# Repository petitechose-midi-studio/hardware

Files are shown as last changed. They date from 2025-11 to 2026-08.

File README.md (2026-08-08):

# MIDI Studio - Hardware Design

Open-source hardware design files for the MIDI Studio controller.

**Teensy 4.1 based MIDI controller with ILI9341 display, 10 rotary encoders, and 15 buttons.**

---

## Hardware Specifications

### Core Components

- **MCU:** Teensy 4.1 (ARM Cortex-M7; hardware rated up to 600 MHz, with MIDI Studio firmware configured at 450 MHz)
- **RAM:** 8 MB PSRAM (**mandatory** - soldered on underside pads)
- **Display:** ILI9341 2.8" TFT (320x240, SPI)
- **Encoders:**
  - 8x Bourns PEC11R rotary encoders (24 PPR, smooth, with push button)
  - 1x Bourns PEC11R rotary encoder (24 PPR, detented, with push button)
  - 1x E38S6G5 optical encoder (600 PPR, high-resolution)
- **Button inputs:** 15 total (6x panel tactile switches + 8x macro-encoder push switches through the multiplexer, plus the NAV encoder push directly on MCU pin 32)
- **Multiplexer:** CD74HC4067 (16-channel analog multiplexer; 14 button inputs used)
- **Connectivity:** USB MIDI (USB-B connector)

### Display Interface (SPI)

- CS = Pin 28
- DC = Pin 0
- RST = Pin 29
- MOSI = Pin 26
- SCK = Pin 27
- MISO = Pin 1
- Firmware-configured SPI speed: 50 MHz

### Power

- USB-powered (5V)
- Teensy 4.1 regulates to 3.3V for peripherals

---

## Repository Contents

### `pcb/`

KiCad PCB design files and manufacturing outputs.

```
pcb/kicad/
midi-studio.kicad_pro      # KiCad project
midi-studio.kicad_sch      # Schematic
midi-studio.kicad_pcb      # PCB layout
midi-studio.step           # 3D model
gerbers/                   # Gerber files for PCB fabrication
bom/                       # Bill of Materials + CPL
pdf/                       # Schematic and assembly drawings (PDF)
```

**PCB Specifications:**
- Layers: 2-layer PCB
- Thickness: 1.6mm
- Surface finish: HASL or ENIG
- Compatible: JLCPCB, PCBWay, OSH Park

---

### `cnc/`

CNC machining files for enclosure fabrication (G-code, DXF).

---

### `keyshot/`

Photorealistic renders for documentation and marketing.

---

## Software Tools

This project was designed using the following software:

- **KiCad** (latest stable version) - PCB schematic and layout design
- **Aspire 12.5** - CNC toolpath generation and G-code export
- **OnShape** - 3D mechanical enclosure design
- **KeyShot** - Photorealistic rendering

All design files are provided in their native formats as well as exported to common interchange formats (PDF, STEP, DXF, Gerber) for maximum compatibility.

---

## 3D Model (OnShape)

**Public OnShape CAD Model:**

**https://cad.onshape.com/documents/a6b73f1c7a20e07680bfab81**

Includes:
- Complete enclosure design
- Mounting holes for all components
- Panel cutouts
- Export-ready for 3D printing or CNC

---

## Bill of Materials (BOM)

### Electronic Components

| Component | Quantity | Part Number | Notes |
|---|---|---|---|
| Teensy 4.1 | 1 | TEENSY41 | **Must have 8MB PSRAM** |
| ILI9341 Display | 1 | 2.8" 320x240 | SPI interface |
| Rotary Encoder (smooth) | 8 | Bourns PEC11R-4220F-S0024 | 24 PPR + button |
| Rotary Encoder (detented) | 1 | Bourns PEC11R-4220K-S0024 | 24 PPR + button |
| Optical Encoder | 1 | E38S6G5 | 600 PPR |
| Tactile Buttons (panel) | 6 | 6mm tactile switch | Panel-mounted |
| Encoder push switches (integrated) | 9 | Included with PEC11R encoders | 8 macro pushes via multiplexer; NAV push direct on MCU pin 32 |
| CD74HC4067 | 1 | CD74HC4067 | Multiplexer IC |
| USB-B Connector | 1 | Standard USB-B | Chassis-mounted |

**Estimated Cost:** ~€80-100 (excluding enclosure)

---

## Manufacturing

### PCB Fabrication

**Recommended:** JLCPCB

**Gerber Files:** `pcb/kicad/gerbers/`

---

### CNC Machining

**Materials:**
- Front panel: Plywood 5mm + 2 thin wood layers 0.6mm
- Bottom panel: Plywood 5mm
- Enclosure: Birch plywood 12mm

---

## Assembly Guide

1. **PCB Assembly** - Solder components, install Teensy 4.1 (verify PSRAM!)
2. **Enclosure Prep** - CNC mill or 3D print parts
3. **Final Assembly** - Mount display, encoders, buttons, PCB
4. **Testing** - Flash firmware, test all inputs

Detailed assembly instructions: See wiki (coming soon)

---

## Related Repositories

- **[Core Firmware](https://github.com/petitechose-midi-studio/core)** - Teensy 4.1 firmware
- **[Bitwig Plugin](https://github.com/petitechose-midi-studio/plugin-bitwig)** - Bitwig Studio extension

---

## License

Licensed under **CERN Open Hardware Licence Version 2 - Strongly Reciprocal (CERN-OHL-S-2.0)**.

### What This Means

**✓ You MAY:**
- Manufacture for **personal use**
- Modify and improve the design
- Share modifications (same license)

**⚠ You MUST (if commercial):**
- Publish all modifications
- Keep the same license
- Provide attribution

**✗ You MAY NOT:**
- Sell without publishing design files

See [LICENSE](LICENSE) for full terms.

---

## Important Notes

### PSRAM is Mandatory

**⚠ Teensy 4.1 MUST have 8MB PSRAM** soldered on underside pads.

Without PSRAM, firmware will NOT run.

Purchase: https://www.pjrc.com/store/psram.html

---

## Support

**Issues:** GitHub Issues

**Commercial Licensing:** <contact@petitechose.audio>

---

**Built by petitechose.audio**

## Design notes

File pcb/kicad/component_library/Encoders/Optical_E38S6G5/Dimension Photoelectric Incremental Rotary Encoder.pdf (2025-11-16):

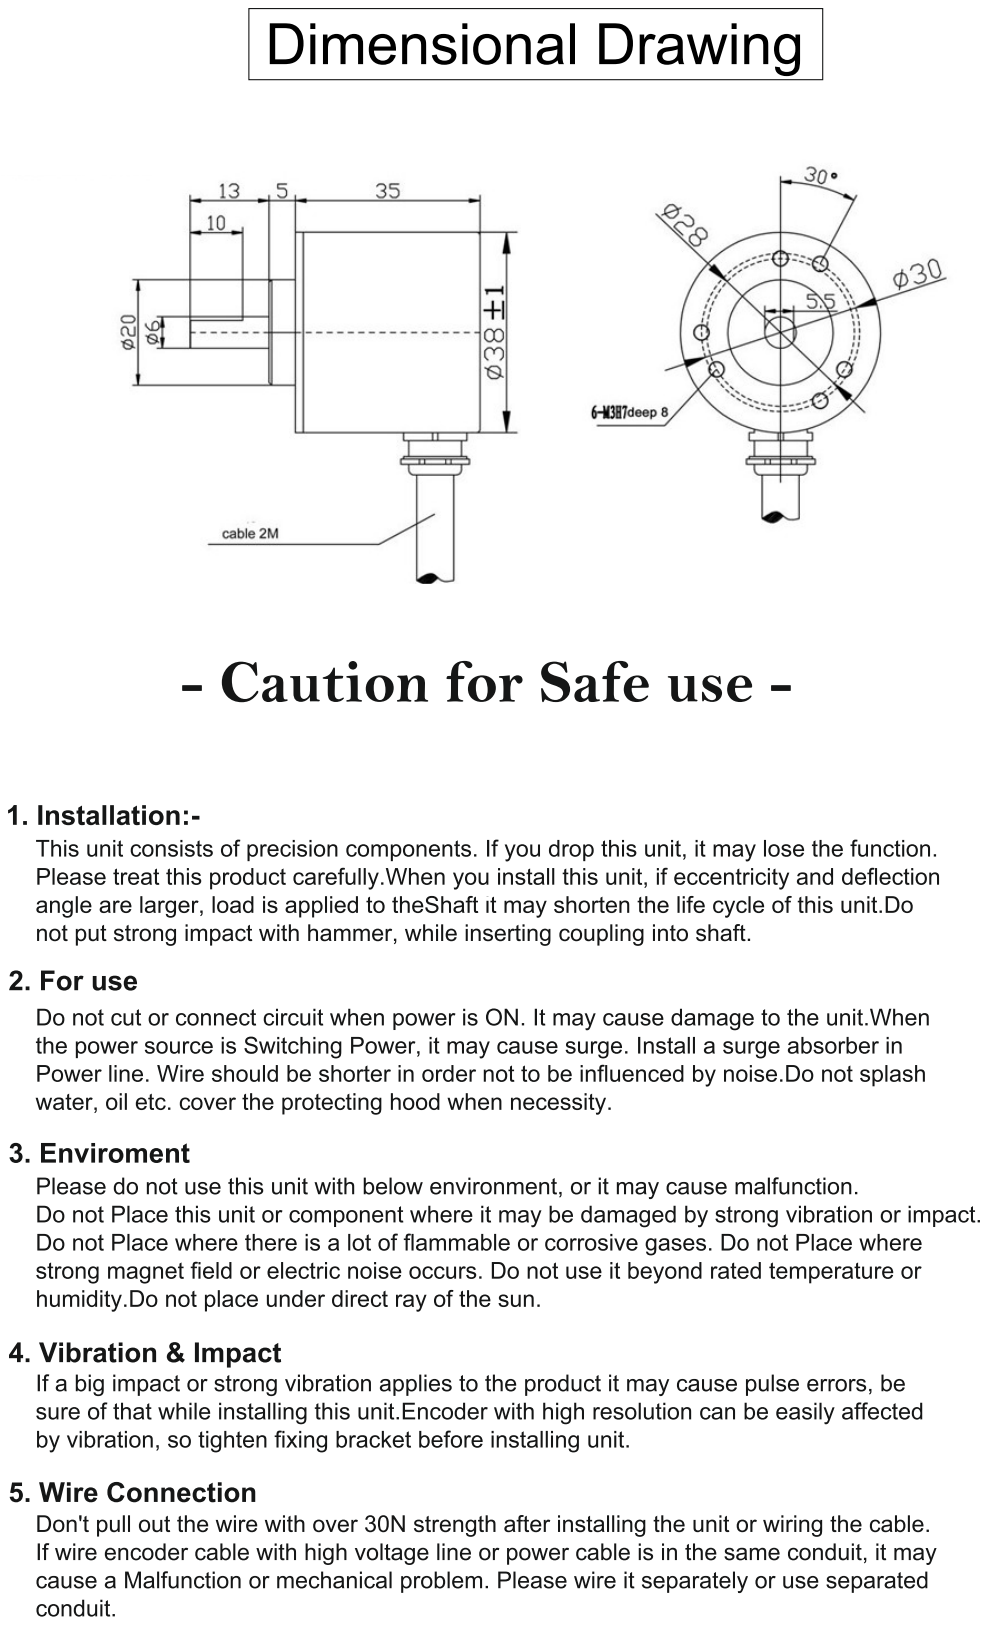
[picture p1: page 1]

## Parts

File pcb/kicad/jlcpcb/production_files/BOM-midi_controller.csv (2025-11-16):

Comment | Designator | Footprint | LCSC | Quantity
~ | FB1,FB2,FB3,FB4 | FB_0805 | C1015 | 4
100nF | C1,C10,C11,C12,C13,C14,C15,C16,C17,C18,C19,C2,C20,C21,C3,C38,C39,C40,C41,C42,C43,C44,C45,C5,C6,C7,C8,C9 | C_0603 | C14663 | 28
100pF | C22 | C_0603 | C14858 | 1
100uF | C23 | C_1206 | C15008 | 1
6N137 | U2 | SOP-8_6.605x9.655mm_P2.54mm | C15825 | 1
10uF | C31,C35,C4 | C_0805 | C15850 | 3
1nF | C24,C37 | C_0603 | C1588 | 2
47uF | C27,C33 | C_0805 | C16780 | 2
1k | R10 | R_0805_2012Metric | C17513 | 1
220 | R11,R12,R9 | R_0805_2012Metric | C17557 | 3
100 | R2,R3,R4,R5 | R_0603_1608Metric | C22775 | 4
220 | R13 | R_0603_1608Metric | C22962 | 1
33Ω | R1,R6,R7,R8 | R_0603 | C23140 | 4
100nF | C25,C26,C28,C30,C32,C34,C36 | C_0805 | C28233 | 7
Conn_01x02_Socket | J10,J11,J4,J5,J7,J9 | JST_XH_B2B-XH-A_1x02_P2.50mm_Vertical_JLC_Constraints | C2908600 | 6
Conn_01x05 | J8 | JST_XH_B5B-XH-A_1x05_P2.50mm_Vertical | C2908603 | 1
Conn_01x24_Socket | J3,J6 | PinSocket_1x24_P2.54mm_Vertical | C41376163 | 2
CD74HC4067M | U1 | SOIC-24W_7.5x15.4mm_P1.27mm | C496123 | 1
74HC14D,653 | U3 | SOIC-14_L8.7-W3.9-P1.27-LS6.0-BL | C5605 | 1
10nF | C29 | C_0603 | C57112 | 1
PESD5V0L1BA,115 | D1,D10,D11,D12,D13,D14,D15,D16,D17,D18,D19,D2,D20,D21,D22,D23,D24,D25,D26,D27,D28,D29,D3,D30,D31,D32,D33,D34,D35,D36,D37,D4,D5,D6,D7,D8,D9 | SOD2512X110N | C85380 | 37
Fuse | F1 | Fuse_0805_2012Metric | C883101 | 1

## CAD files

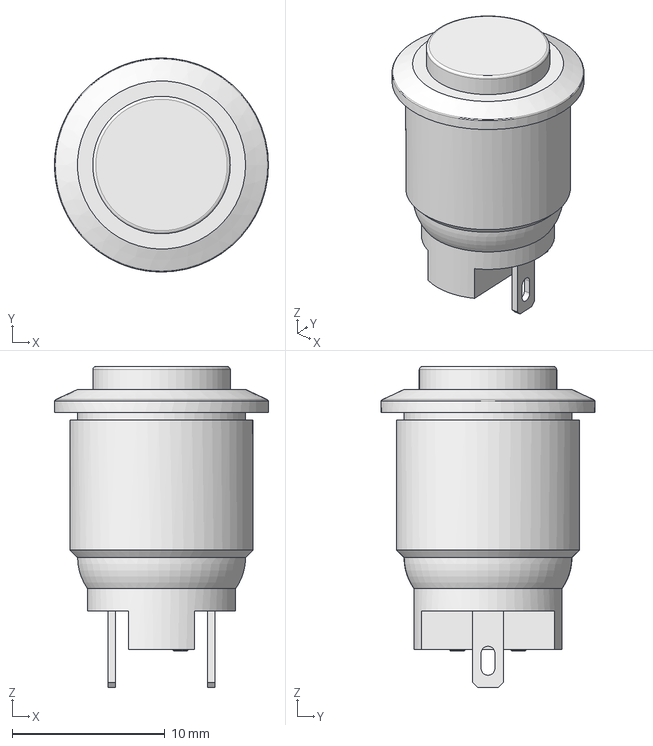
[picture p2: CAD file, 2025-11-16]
pcb/kicad/component_library/Buttons/PV0H240/PUSH_BUTTON_PV0H240xx.step
14.0 x 14.0 x 21.0 mm

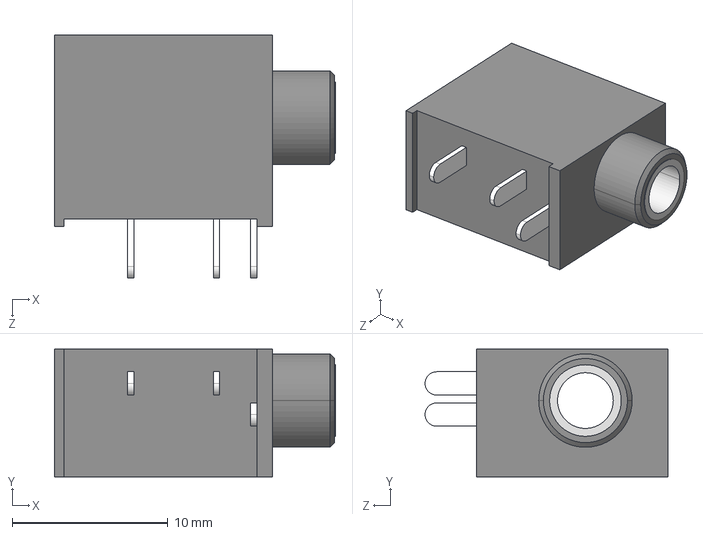
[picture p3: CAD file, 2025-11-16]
pcb/kicad/component_library/Connector/Audio/Same_Sky_SJ1-3533NG.step
18.1 x 8.20 x 15.6 mm

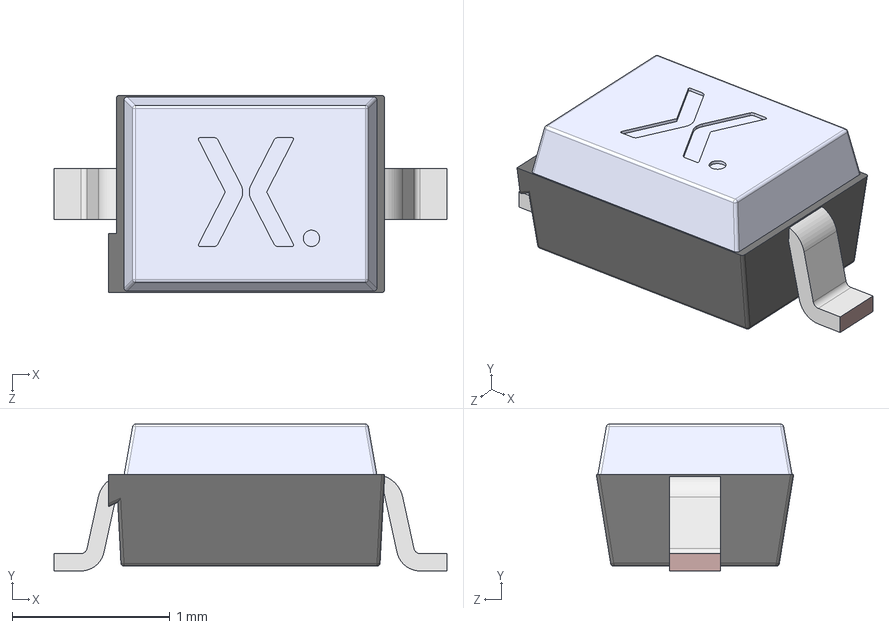
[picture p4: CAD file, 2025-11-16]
pcb/kicad/component_library/Diode/PESD5V0L1BA,115/3D/PESD5V0L1BA,115.stp
2.49 x 0.93 x 1.25 mm
SOD323 Lower body
SOD323 Lead x 2
SOD323 Upper body

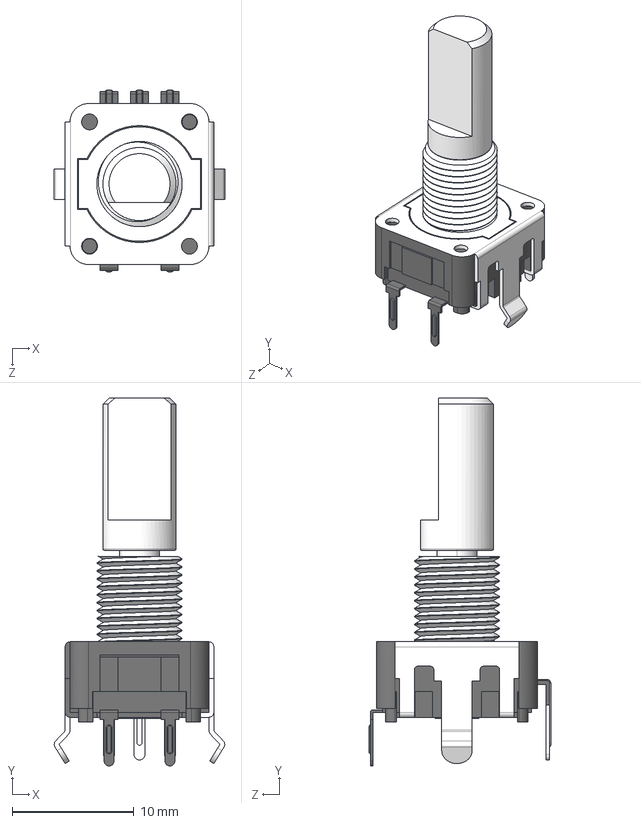
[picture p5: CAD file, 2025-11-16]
pcb/kicad/component_library/Encoders/Mecanical_PEC11R/PEC11R-4020F-S0024.stp
14.0 x 30.2 x 14.9 mm

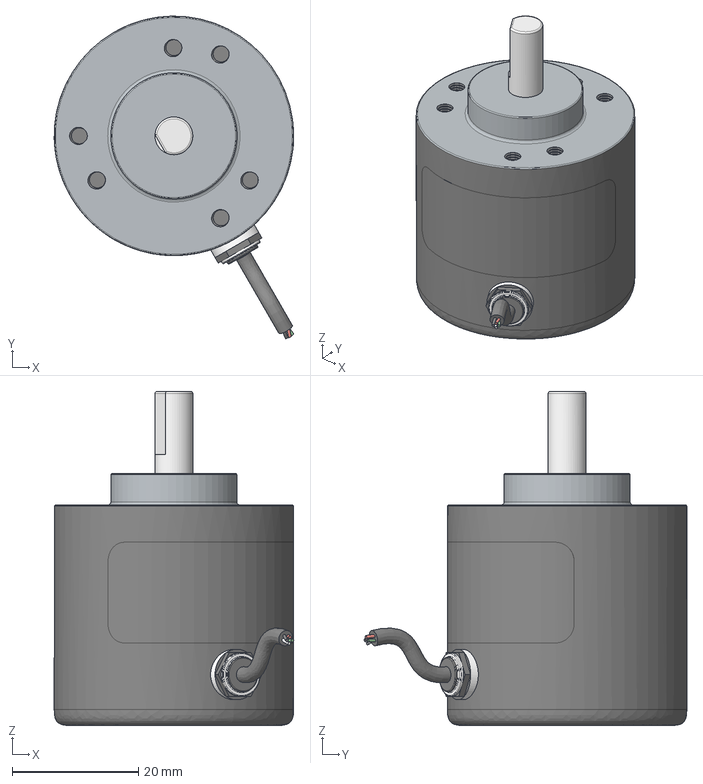
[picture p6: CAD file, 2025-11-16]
pcb/kicad/component_library/Encoders/Optical_E38S6G5/OPTICAL_ENCODER.step
38.0 x 51.2 x 53.0 mm

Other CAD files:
pcb/kicad/component_library/Microcontrollers/Teensy/Teensy 4.1.x_b

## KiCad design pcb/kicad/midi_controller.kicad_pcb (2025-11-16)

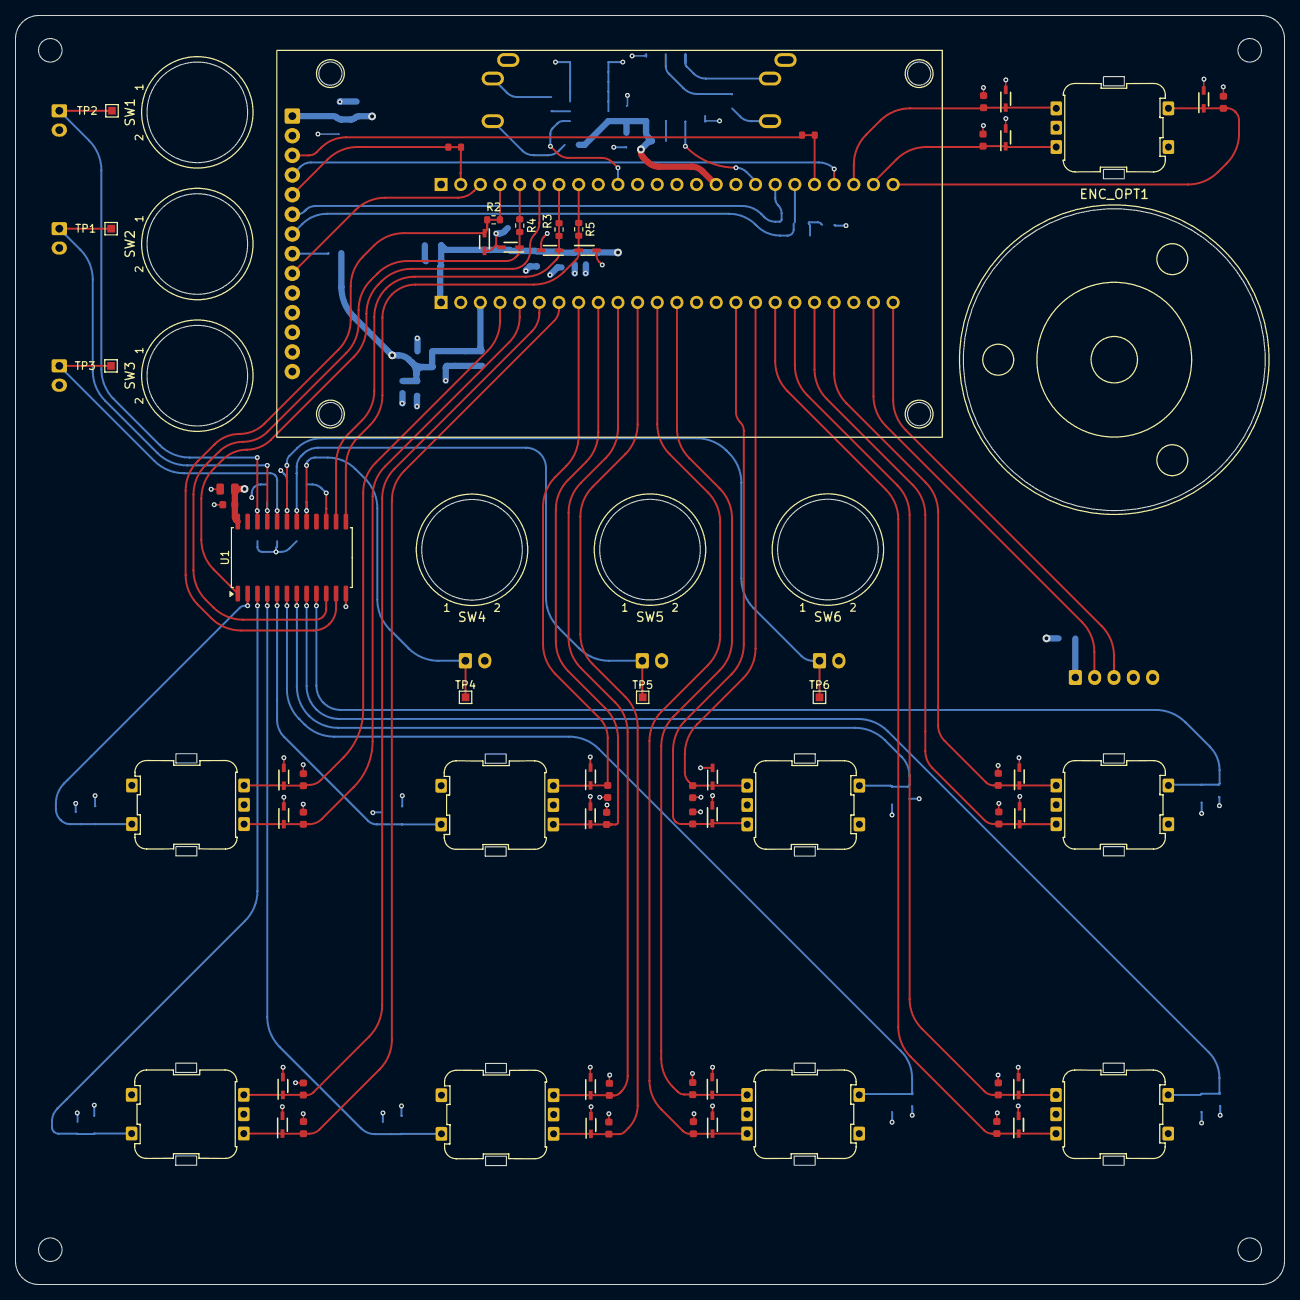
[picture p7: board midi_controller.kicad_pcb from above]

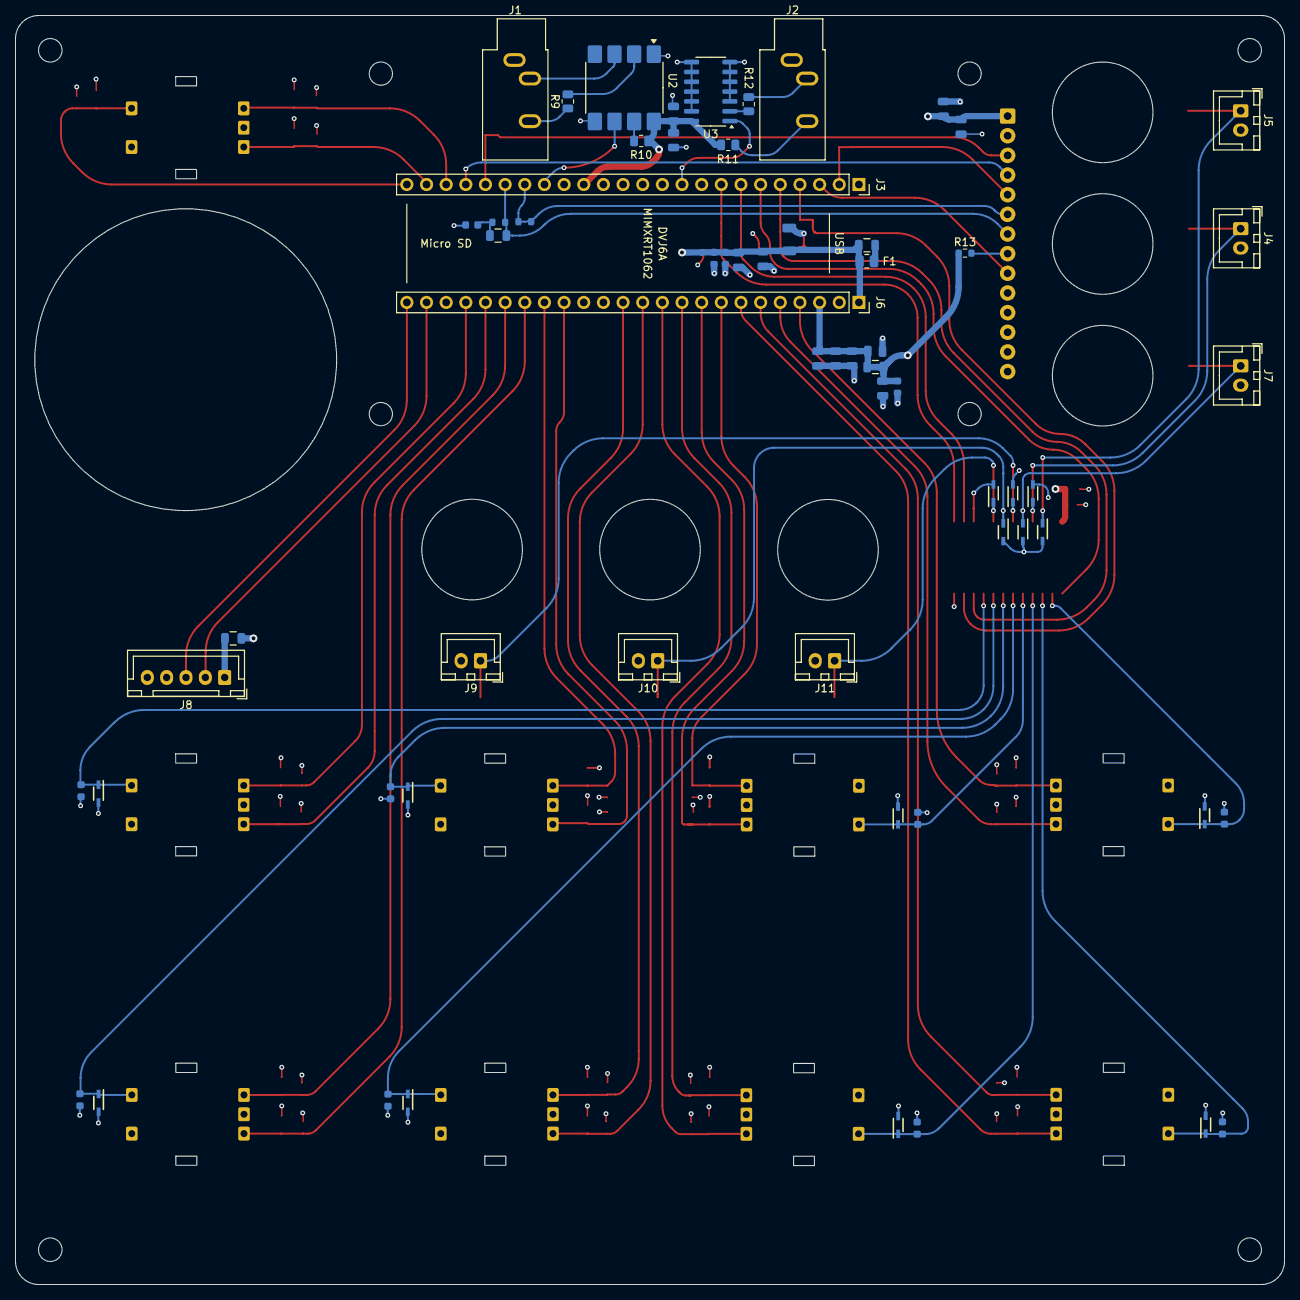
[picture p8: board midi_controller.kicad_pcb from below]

Board: 4 copper layers, 164.0 x 164.0 mm, 138 parts (64 on the bottom side), 63 nets.

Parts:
C1, C2, C3, C5, C6, C7, C8, C9, C10, C11, C12, C13, C14, C15, C16, C17, C18, C19, C20, C21, C38, C39, C40, C41, C42, C43, C44, C45: 100nF; C_0603
C4, C31, C35: 10uF; C_0805
C22: 100pF; C_0603
C23: 100uF; C_1206
C24, C37: 1nF; C_0603
C25, C26, C28, C30, C32, C34, C36: 100nF; C_0805
C27, C33: 47uF; C_0805
C29: 10nF; C_0603
D1, D2, D3, D4, D5, D6, D7, D8, D9, D10, D11, D12, D13, D14, D15, D16, D17, D18, D19, D20, D21, D22, D23, D24, D25, D26, D27, D28, D29, D30, D31, D32, D33, D34, D35, D36, D37: PESD5V0L1BA,115; SOD2512X110N
DISP1: MIDI_Display_MSP2807; MSP2807_ILI9341_Display
ENC_MECH1, ENC_MECH2, ENC_MECH3, ENC_MECH4, ENC_MECH5, ENC_MECH6, ENC_MECH7, ENC_MECH8, ENC_MECH9: MIDI_Encoder_PEC11R; PEC11R4220FS0024
ENC_OPT1: MIDI_Encoder_E38S6G5_Optical; E38S6G5_Optical_Encoder
F1: Fuse; Fuse_0805_2012Metric
FB1, FB2, FB3, FB4: FB_0805
J1: MIDI In; Jack_3.5mm_CUI_SJ1-3533NG_Horizontal
J2: MIDI Out; Jack_3.5mm_CUI_SJ1-3533NG_Horizontal
J3, J6: Conn_01x24_Socket; PinSocket_1x24_P2.54mm_Vertical
J4, J5, J7, J9, J10, J11: Conn_01x02_Socket; JST_XH_B2B-XH-A_1x02_P2.50mm_Vertical_JLC_Constraints
J8: Conn_01x05; JST_XH_B5B-XH-A_1x05_P2.50mm_Vertical
MCU1: MIDI_Teensy4.1; Teensy41_Mechanical
R1, R6, R7, R8: 33Ω; R_0603
R2, R3, R4, R5: 100; R_0603_1608Metric
R9, R11, R12: 220; R_0805_2012Metric
R10: 1k; R_0805_2012Metric
R13: 220; R_0603_1608Metric
SW1, SW2, SW3, SW4, SW5, SW6: PV0H24011_Pushbutton
TP1, TP2, TP3, TP4, TP5, TP6: TestPoint; TestPoint_Pad_1.0x1.0mm
U1: CD74HC4067M; SOIC-24W_7.5x15.4mm_P1.27mm
U2: 6N137; SOP-8_6.605x9.655mm_P2.54mm
U3: 74HC14D,653; SOIC-14_L8.7-W3.9-P1.27-LS6.0-BL

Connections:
+3V3_A: C4.1, C5.1, C32.1, C33.1, C34.1, C35.1, C36.1, C37.1, FB3.1, FB3.2, J6.3, R13.1, U1.24 (VCC)
+3V3_B: C26.1, C28.2, J3.15, R10.2, R11.1, U2.8 (VCC), U3.14 (VCC)
+5V: C23.1, C24.1, C25.1, C27.1, C29.1, C30.2, C31.1, DISP1.1 (VCC), F1.1, FB2.1, FB4.2, J6.1
/Buttons_Momentary/BUTTON_PUSH_MOM_01: D26.1 (K1), J5.1, TP2.1, U1.22 (I9)
/Buttons_Momentary/BUTTON_PUSH_MOM_02: D29.1 (K1), J4.1, TP1.1, U1.21 (I10)
/Buttons_Momentary/BUTTON_PUSH_MOM_03: D28.1 (K1), J7.1, TP3.1, U1.20 (I11)
/Buttons_Momentary/BUTTON_PUSH_MOM_04: D27.1 (K1), J9.1, TP6.1, U1.19 (I12)
/Buttons_Momentary/BUTTON_PUSH_MOM_05: D24.1 (K1), J10.1, TP5.1, U1.18 (I13)
/Buttons_Momentary/BUTTON_PUSH_MOM_06: D25.1 (K1), J11.1, TP4.1, U1.17 (I14)
/COM: J3.6, U1.1 (COM)
/CS: DISP1.3 (CS), J3.20, R6.1, R6.2
/DC: DISP1.5 (DC), J3.2, R1.1, R1.2
/LED: DISP1.8 (LED), R13.2
/MIDI_Encoder_Matrix_2x4_with_push_buttons/1x1.QUAD_A: C7.2, D9.1 (K1), ENC_MECH2.A, J6.5
/MIDI_Encoder_Matrix_2x4_with_push_buttons/1x1.QUAD_B: C6.2, D8.1 (K1), ENC_MECH2.B, J6.4
/MIDI_Encoder_Matrix_2x4_with_push_buttons/1x1_SW_A: C41.2, D33.1 (K1), ENC_MECH2.1 (SW1), U1.2 (I7)
/MIDI_Encoder_Matrix_2x4_with_push_buttons/1x2.QUAD_A: C8.2, D11.1 (K1), ENC_MECH3.A, J6.9
/MIDI_Encoder_Matrix_2x4_with_push_buttons/1x2.QUAD_B: C9.2, D10.1 (K1), ENC_MECH3.B, J6.8
/MIDI_Encoder_Matrix_2x4_with_push_buttons/1x2_SW_A: C40.2, D32.1 (K1), ENC_MECH3.1 (SW1), U1.5 (I4)
/MIDI_Encoder_Matrix_2x4_with_push_buttons/1x3.QUAD_A: C10.2, D12.1 (K1), ENC_MECH4.A, J6.17
/MIDI_Encoder_Matrix_2x4_with_push_buttons/1x3.QUAD_B: C11.2, D13.1 (K1), ENC_MECH4.B, J6.16
/MIDI_Encoder_Matrix_2x4_with_push_buttons/1x3_SW_A: C39.2, D31.1 (K1), ENC_MECH4.1 (SW1), U1.7 (I2)
/MIDI_Encoder_Matrix_2x4_with_push_buttons/1x4.QUAD_A: C12.2, D14.1 (K1), ENC_MECH5.A, J6.21
/MIDI_Encoder_Matrix_2x4_with_push_buttons/1x4.QUAD_B: C13.2, D15.1 (K1), ENC_MECH5.B, J6.20
/MIDI_Encoder_Matrix_2x4_with_push_buttons/1x4_SW_A: C38.2, D30.1 (K1), ENC_MECH5.1 (SW1), U1.9 (I0)
/MIDI_Encoder_Matrix_2x4_with_push_buttons/2x1.QUAD_A: C14.2, D17.1 (K1), ENC_MECH6.A, J6.7
/MIDI_Encoder_Matrix_2x4_with_push_buttons/2x1.QUAD_B: C15.2, D16.1 (K1), ENC_MECH6.B, J6.6
/MIDI_Encoder_Matrix_2x4_with_push_buttons/2x1_SW_A: C45.2, D37.1 (K1), ENC_MECH6.1 (SW1), U1.3 (I6)
/MIDI_Encoder_Matrix_2x4_with_push_buttons/2x2.QUAD_A: C16.2, D18.1 (K1), ENC_MECH7.A, J6.11
/MIDI_Encoder_Matrix_2x4_with_push_buttons/2x2.QUAD_B: C17.2, D19.1 (K1), ENC_MECH7.B, J6.10
/MIDI_Encoder_Matrix_2x4_with_push_buttons/2x2_SW_A: C44.2, D36.1 (K1), ENC_MECH7.1 (SW1), U1.4 (I5)
/MIDI_Encoder_Matrix_2x4_with_push_buttons/2x3.QUAD_A: C19.2, D20.1 (K1), ENC_MECH8.A, J6.13
/MIDI_Encoder_Matrix_2x4_with_push_buttons/2x3.QUAD_B: C18.2, D21.1 (K1), ENC_MECH8.B, J6.12
/MIDI_Encoder_Matrix_2x4_with_push_buttons/2x3_SW_A: C43.2, D35.1 (K1), ENC_MECH8.1 (SW1), U1.6 (I3)
/MIDI_Encoder_Matrix_2x4_with_push_buttons/2x4.QUAD_A: C20.2, D22.1 (K1), ENC_MECH9.A, J6.19
/MIDI_Encoder_Matrix_2x4_with_push_buttons/2x4.QUAD_B: C21.2, D23.1 (K1), ENC_MECH9.B, J6.18
/MIDI_Encoder_Matrix_2x4_with_push_buttons/2x4_SW_A: C42.2, D34.1 (K1), ENC_MECH9.1 (SW1), U1.8 (I1)
/MISO: DISP1.9 (SDO/MISO), J3.3
/MOSI: DISP1.6 (SDI/MOSI), J3.18, R8.1, R8.2
/NAV.QUAD_A: C1.2, D1.1 (K1), ENC_MECH1.A, J3.22
/NAV.QUAD_B: C2.2, D7.1 (K1), ENC_MECH1.B, J3.23
/NAV.SW: C3.2, D2.1 (K1), ENC_MECH1.1 (SW1), J3.24
/OPT.QUAD_A: J6.23, J8.2
/OPT.QUAD_B: J6.24, J8.3
/RST: DISP1.4 (RST), J3.21
/RX6: J3.17, U2.6 (VO)
/S0: D5.1 (K1), J3.5, R4.1, R4.2, U1.10 (S0)
/S1: D3.1 (K1), J3.4, R2.1, R2.2, U1.11 (S1)
/S2: D6.1 (K1), J3.7, R3.1, R3.2, U1.14 (S2)
/S3: D4.1 (K1), J3.8, R5.1, R5.2, U1.13 (S3)
/SCK: DISP1.7 (SCK), FB1.1, J3.19, R7.2
/TX2: J3.10, U3.1 (1A)
GND: C1.1, C2.1, C3.1, C4.2, C5.2, C6.1, C7.1, C8.1, C9.1, C10.1, C11.1, C12.1, C13.1, C14.1, C15.1, C16.1, C17.1, C18.1, C19.1, C20.1, C21.1, C22.2, C23.2, C24.2, C25.2, C26.2, C27.2, C28.1, C29.2, C30.1, C31.2, C32.2, C33.2, C34.2, C35.2, C36.2, C37.2, C38.1, C39.1, C40.1, C41.1, C42.1, C43.1, C44.1, C45.1, D1.2 (K2), D2.2 (K2), D3.2 (K2), D4.2 (K2), D5.2 (K2), D6.2 (K2), D7.2 (K2), D8.2 (K2), D9.2 (K2), D10.2 (K2), D11.2 (K2), D12.2 (K2), D13.2 (K2), D14.2 (K2), D15.2 (K2), D16.2 (K2), D17.2 (K2), D18.2 (K2), D19.2 (K2), D20.2 (K2), D21.2 (K2), D22.2 (K2), D23.2 (K2), D24.2 (K2), D25.2 (K2), D26.2 (K2), D27.2 (K2), D28.2 (K2), D29.2 (K2), D30.2 (K2), D31.2 (K2), D32.2 (K2), D33.2 (K2), D34.2 (K2), D35.2 (K2), D36.2 (K2), D37.2 (K2), DISP1.2 (GND), ENC_MECH1.2 (GND), ENC_MECH1.C (GND), ENC_MECH2.2 (GND), ENC_MECH2.C (GND), ENC_MECH3.2 (GND), ENC_MECH3.C (GND), ENC_MECH4.2 (GND), ENC_MECH4.C (GND), ENC_MECH5.2 (GND), ENC_MECH5.C (GND), ENC_MECH6.2 (GND), ENC_MECH6.C (GND), ENC_MECH7.2 (GND), ENC_MECH7.C (GND), ENC_MECH8.2 (GND), ENC_MECH8.C (GND), ENC_MECH9.2 (GND), ENC_MECH9.C (GND), J1.S, J2.S, J3.1, J4.2, J5.2, J6.2, J6.15, J7.2, J8.4, J8.5, J9.2, J10.2, J11.2, U1.12 (GND), U1.15 (~E), U2.1 (NC), U2.5 (GND), U3.3 (2A), U3.4 (2Y), U3.5 (3A), U3.6 (3Y), U3.7 (GND), U3.8 (4Y), U3.9 (4A), U3.10 (5Y), U3.11 (5A), U3.12 (6Y), U3.13 (6A)
unnamed: C22.1, FB1.2, R7.1
unnamed: F1.2, FB2.2
unnamed: J1.R, R9.1
unnamed: J2.R, R11.2
unnamed: J2.T, R12.2
unnamed: FB4.1, J8.1
unnamed: R9.2, U2.2 (A)
unnamed: J1.T, U2.3 (C)
unnamed: R10.1, U2.7 (EN)
unnamed: R12.1, U3.2 (1Y)

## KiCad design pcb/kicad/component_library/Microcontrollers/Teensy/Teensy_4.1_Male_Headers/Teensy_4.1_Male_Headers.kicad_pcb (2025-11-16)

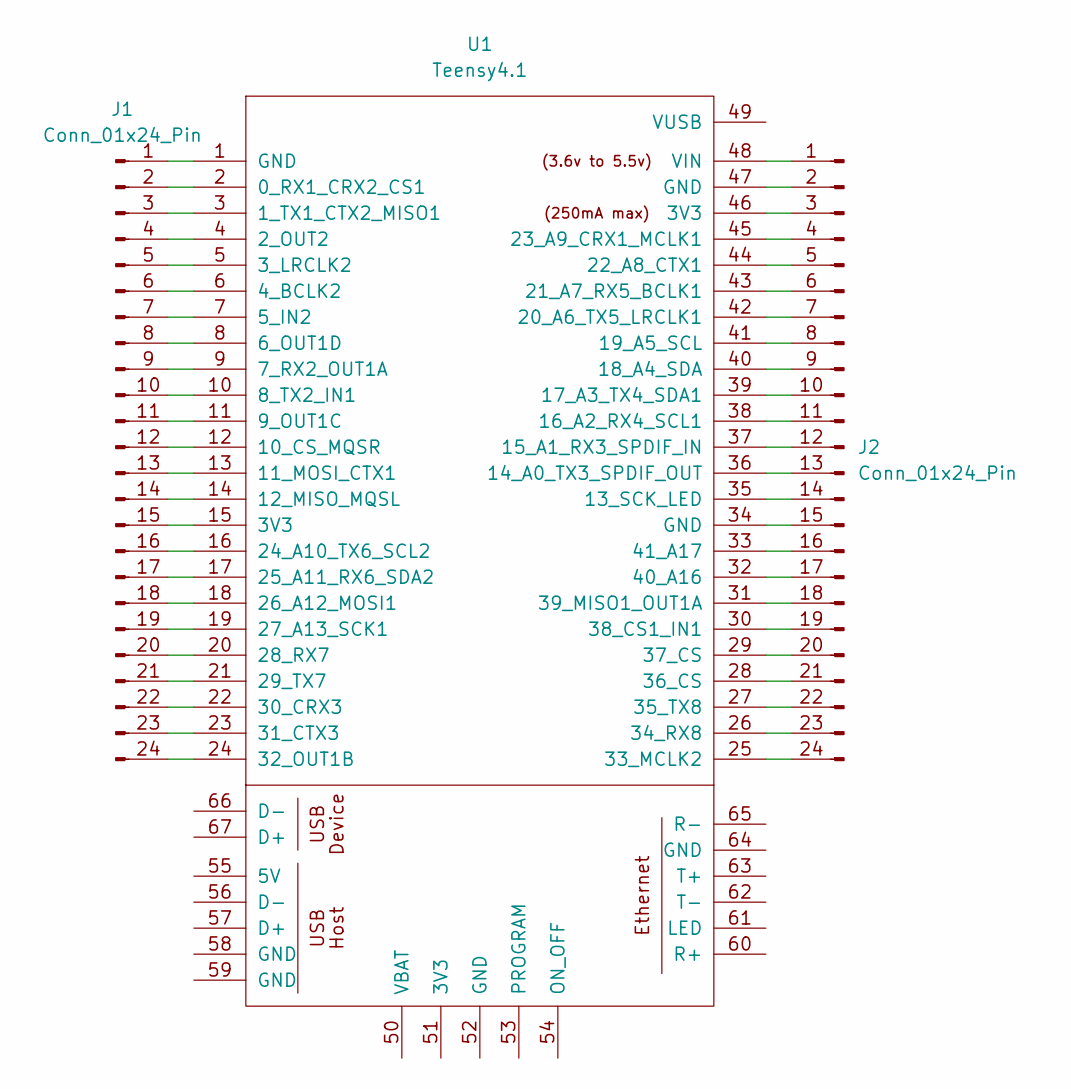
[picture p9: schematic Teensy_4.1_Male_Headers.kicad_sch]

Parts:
J1, J2: Conn_01x24_Pin; PinHeader_1x24_P2.54mm_Vertical
U1: Teensy4.1; Teensy41

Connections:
unnamed: J1.1, U1.1 (GND)
unnamed: J1.2, U1.2 (0_RX1_CRX2_CS1)
unnamed: J1.3, U1.3 (1_TX1_CTX2_MISO1)
unnamed: J1.4, U1.4 (2_OUT2)
unnamed: J1.5, U1.5 (3_LRCLK2)
unnamed: J1.6, U1.6 (4_BCLK2)
unnamed: J1.7, U1.7 (5_IN2)
unnamed: J1.8, U1.8 (6_OUT1D)
unnamed: J1.9, U1.9 (7_RX2_OUT1A)
unnamed: J1.10, U1.10 (8_TX2_IN1)
unnamed: J1.11, U1.11 (9_OUT1C)
unnamed: J1.12, U1.12 (10_CS_MQSR)
unnamed: J1.13, U1.13 (11_MOSI_CTX1)
unnamed: J1.14, U1.14 (12_MISO_MQSL)
unnamed: J1.15, U1.15 (3V3)
unnamed: J1.16, U1.16 (24_A10_TX6_SCL2)
unnamed: J1.17, U1.17 (25_A11_RX6_SDA2)
unnamed: J1.18, U1.18 (26_A12_MOSI1)
unnamed: J1.19, U1.19 (27_A13_SCK1)
unnamed: J1.20, U1.20 (28_RX7)
unnamed: J1.21, U1.21 (29_TX7)
unnamed: J1.22, U1.22 (30_CRX3)
unnamed: J1.23, U1.23 (31_CTX3)
unnamed: J1.24, U1.24 (32_OUT1B)
unnamed: J2.1, U1.48 (VIN)
unnamed: J2.2, U1.47 (GND)
unnamed: J2.3, U1.46 (3V3)
unnamed: J2.4, U1.45 (23_A9_CRX1_MCLK1)
unnamed: J2.5, U1.44 (22_A8_CTX1)
unnamed: J2.6, U1.43 (21_A7_RX5_BCLK1)
unnamed: J2.7, U1.42 (20_A6_TX5_LRCLK1)
unnamed: J2.8, U1.41 (19_A5_SCL)
unnamed: J2.9, U1.40 (18_A4_SDA)
unnamed: J2.10, U1.39 (17_A3_TX4_SDA1)
unnamed: J2.11, U1.38 (16_A2_RX4_SCL1)
unnamed: J2.12, U1.37 (15_A1_RX3_SPDIF_IN)
unnamed: J2.13, U1.36 (14_A0_TX3_SPDIF_OUT)
unnamed: J2.14, U1.35 (13_SCK_LED)
unnamed: J2.15, U1.34 (GND)
unnamed: J2.16, U1.33 (41_A17)
unnamed: J2.17, U1.32 (40_A16)
unnamed: J2.18, U1.31 (39_MISO1_OUT1A)
unnamed: J2.19, U1.30 (38_CS1_IN1)
unnamed: J2.20, U1.29 (37_CS)
unnamed: J2.21, U1.28 (36_CS)
unnamed: J2.22, U1.27 (35_TX8)
unnamed: J2.23, U1.26 (34_RX8)
unnamed: J2.24, U1.25 (33_MCLK2)

Board: 2 copper layers, 3 parts (2 on the bottom side), 48 nets, no tracks yet.

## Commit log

2025-11-16 Initial commit: MIDI Studio hardware design files
    Add complete open-source hardware design for Teensy 4.1-based MIDI
    controller:
    Hardware specifications:
    - Teensy 4.1 MCU with 8MB PSRAM (mandatory)
    - ILI9341 2.8" TFT display (320x240, SPI)
    - 10 rotary encoders (8 smooth + 1 detented + 1 optical 600 PPR)
    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
    [2.8inch_MSP2807_PCB_Package_Library.PcbLib, 2.8inch_MSP2807_Schematic_Package_Library.SchLib, BOM-midi_controller.csv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]
2026-07-05 chore: ignore KiCad history artifacts
2026-07-13 docs: correct display pins and SPI speed
2026-08-08 docs: correct controller clock and button routing
